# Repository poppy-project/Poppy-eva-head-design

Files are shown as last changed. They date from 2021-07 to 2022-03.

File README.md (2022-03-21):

# Poppy-eva-head-design

Raspberry Pi 4-based head design for Poppy Torso and Humanoid ; embedding a screen: the work was done by 3 students of the ENSAM Bachelor of technology at Bordeaux, France: Damien MARTY, Clément GEA and Éléa CHARPNTIER, under the supervison of Jean-Luc CHARLES and Cécile DELARUE, professors at ENSAM Bordeaux.

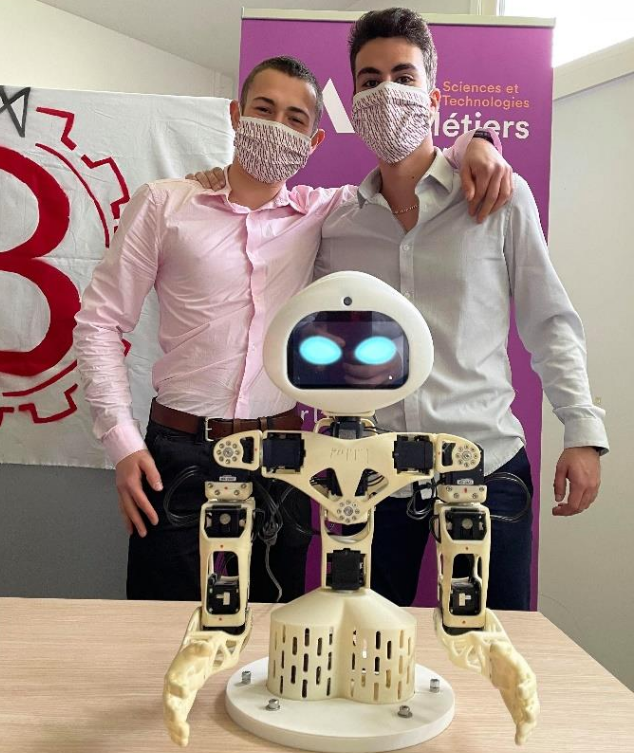
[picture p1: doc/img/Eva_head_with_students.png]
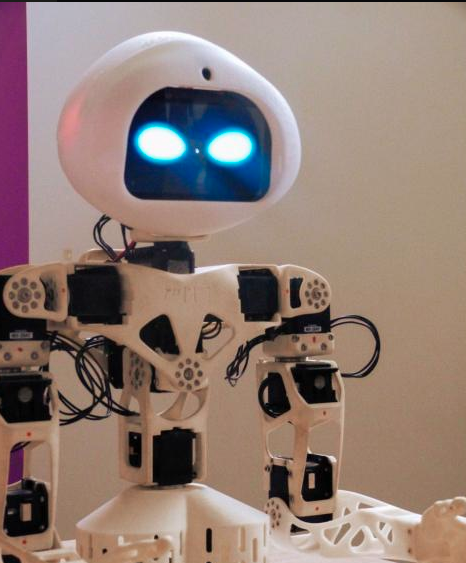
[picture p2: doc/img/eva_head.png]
  

This repository contains:

* `doc` contains the documentation files on the Poppy Eva head:
  * `Eva_head_design.pdf` gives the design history of the head Eva.
  * `Eva_head_assemby_procedure.md` is the assembly guide to make the Eva head for the Poppy Torso or Humanoid.
* `hardware`
  * `STL` : contains the STL files to print the four parts that make the Eva head.
  * `BOM.md`: the bill of material.
* `software`: contains the instructions to customize the file `config.txt` in the `boot` partition of the SD card in order to use the DSI connector of the RPI4 to connect the display screen. A full example of `config.txt` is also given.

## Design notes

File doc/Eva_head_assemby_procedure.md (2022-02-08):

# Eva-Head  assembly procedure

With [this bill of materials](../hardware/BOM.md), you should have all this material on the work bench:

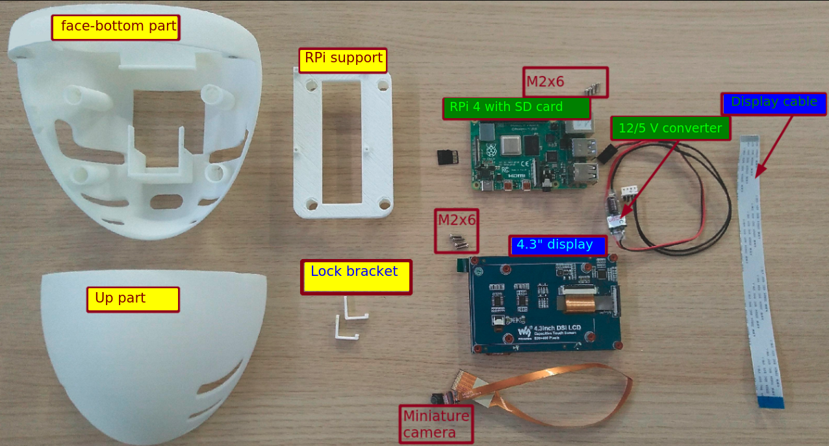
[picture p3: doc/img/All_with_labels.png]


## 1 - Preparing the head parts

Insert the miniature button magnets in the holes provided for this purpose in the _bottom/face_ and _upper_ parts.

WARNING: be careful with the magnet orientation while inserting them. __north__ and __south__ poles attract each other ensuring magnetic attraction between the the _up_ and _face-bottom_ parts, while __north__/__north__ or __south__/__south__ repel each other !

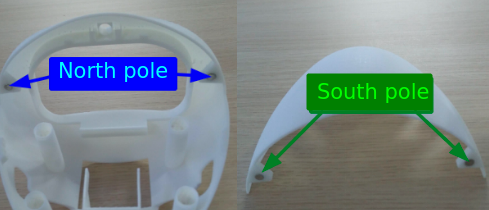
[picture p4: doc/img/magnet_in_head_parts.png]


## 2 - Fix the "bottom-face part" of the head to the AX-12 motor

- Insert the 8 x _M2 nuts_ in the reserved slots on the carter of the AX-12 motor

- Engage the "bottom-face part" of the head to align its fixing holes with those of the housing of the AX-12 motor.

- Gently tighten the 8 _M2x6_ screws:

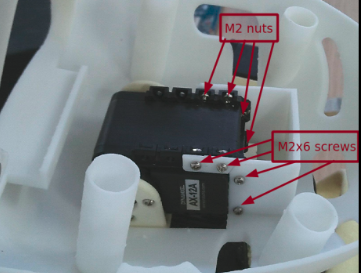
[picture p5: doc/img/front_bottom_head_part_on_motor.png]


## 3 - Preparing and installing the LCD display

- Gently pull the extremities of the _black lock bar_ of the DSI connector to open the connector.

- Insert the display cable with the contacts side of the cable oriented as shown in the image.
  
- Gently push the extremities of the _black lock bar_  to lock the cable inside the connector.

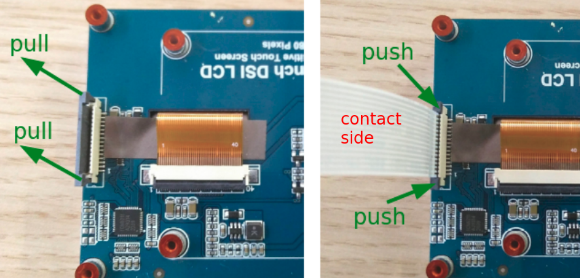
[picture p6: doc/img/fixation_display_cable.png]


When done, engage the screen in the "bottom-face part" of the head and lock the display with the the help of "removable glue pads" (_yellow patafix_) with the 2 _lock sliders_ :

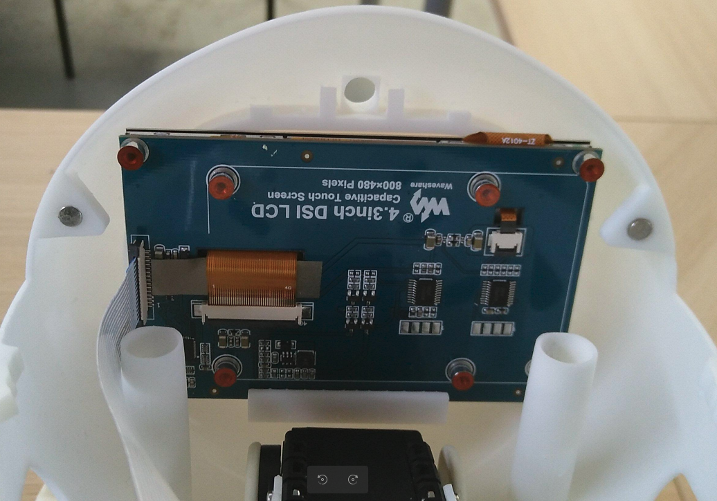
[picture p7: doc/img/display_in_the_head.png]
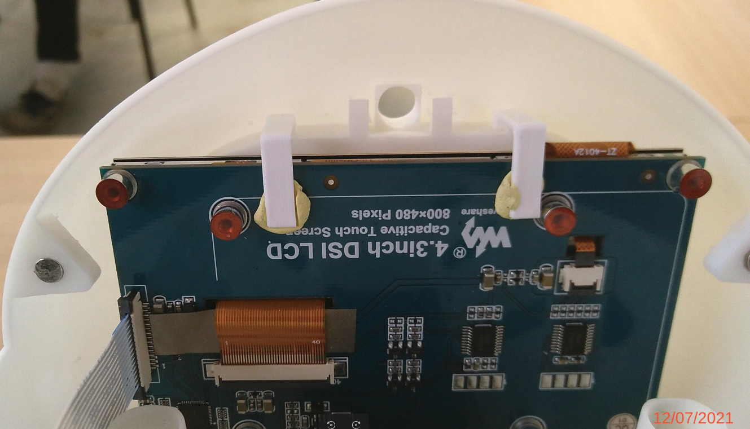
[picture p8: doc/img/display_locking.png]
 

## 4 - Fixing the camera in the head 

Insert the camera in the hole in the "bottom-face part" of the head:

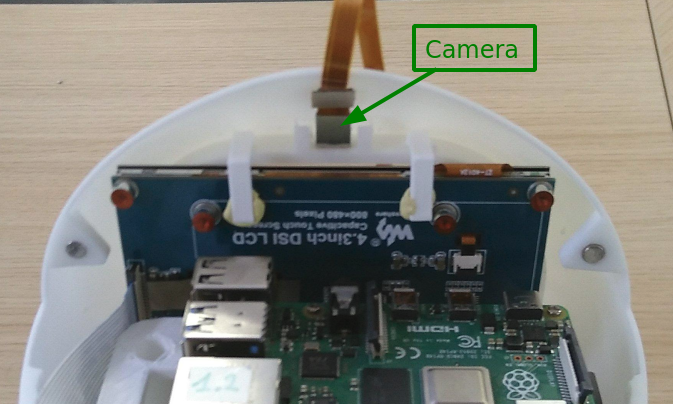
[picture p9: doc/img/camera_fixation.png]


## 5 - Preparing the RPi module

- You must flash the SD card to install a Linux distribution and the Poppy software: follow this [guide](https://github.com/poppy-project/poppy-docs/blob/master/en/installation/burn-an-image-file.md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).<br>Then you can insert the SD card in the SD slot of the RPi module.

- Place the RPi module on the "RPi support" part as shown in the image and gently tighten the 4 x M2x6 screws:

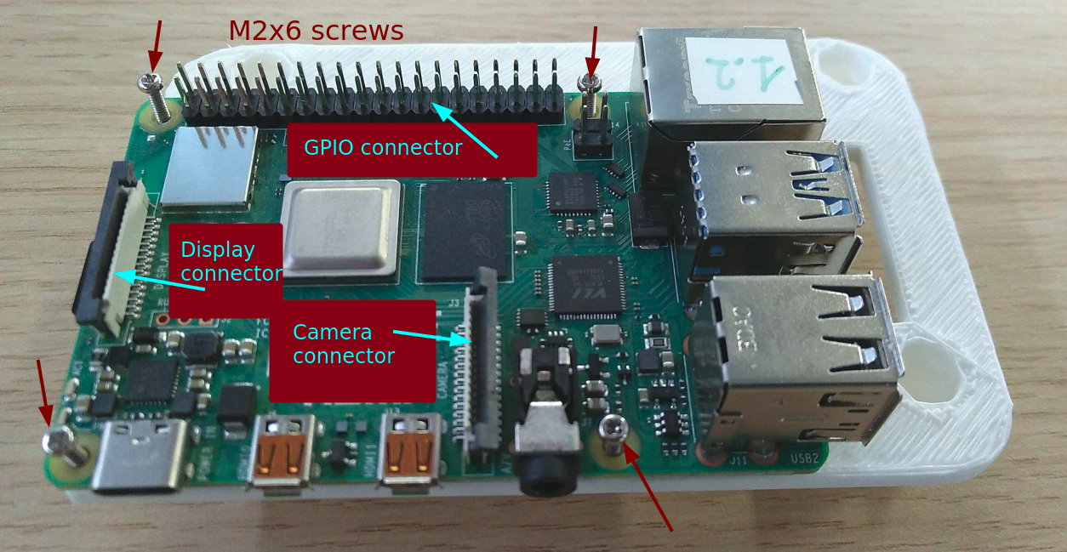
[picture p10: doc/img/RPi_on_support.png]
 

- When done, you can place the RPi support in the "bottom-face part" of the head, with the GPIO connector at the raer of the head.

## 6 - Final steps

- Connect the camera cable to the camera connector of the RPi module as shown in the image, with the contacts side of the cable facing the connector contacts (same gentle operation as in step 3).

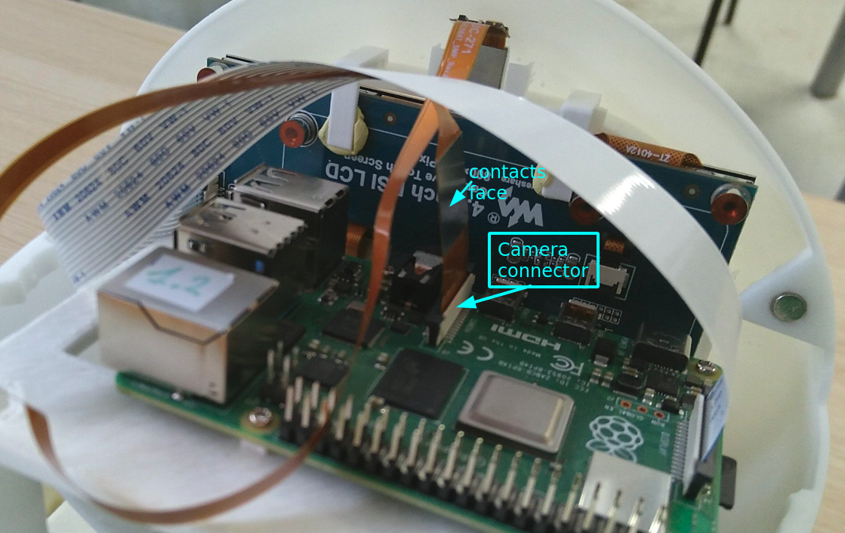
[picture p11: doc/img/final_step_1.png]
 

- Connect the display cable to the RPi display connector as shown in the image, with contact side of the cable facing the connector contacts.
  
- Connect the power connector to the GPIO connector of the RPi module as shown in the image.

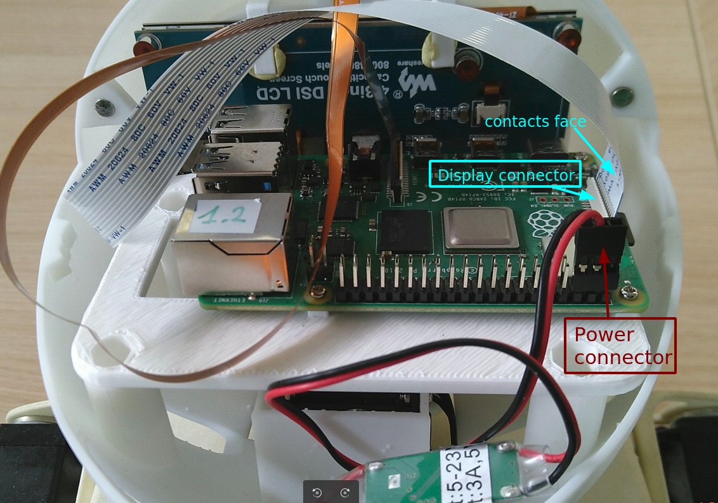
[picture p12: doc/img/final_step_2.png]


- Connect the USB2AXB to the USB port of the RPi module:
  
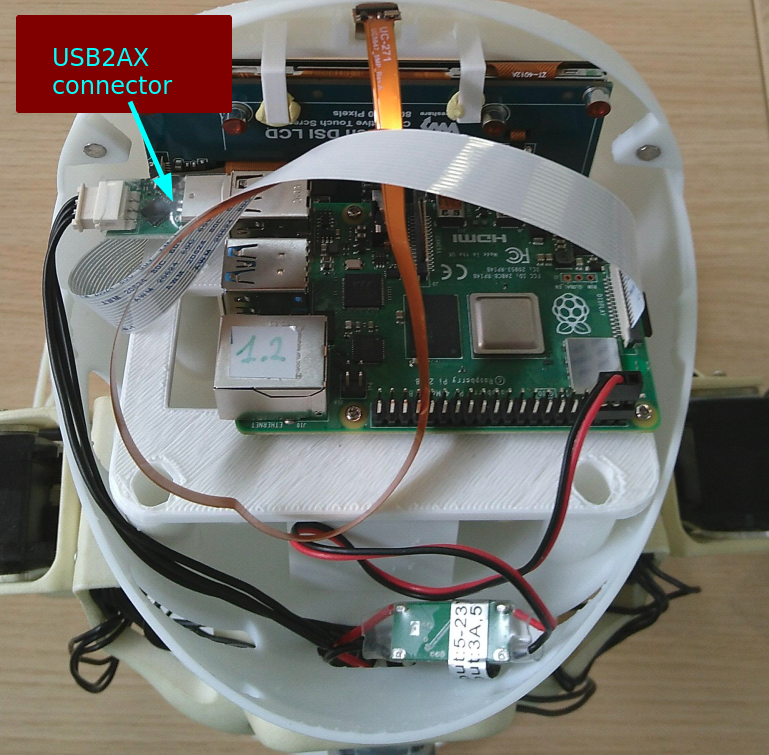
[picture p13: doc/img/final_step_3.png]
 

Et Voilà :smirk:

Close the head with the "upper part" : the Poppy _Eva head_ is ready ....

eva head

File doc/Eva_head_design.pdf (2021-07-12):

# POPPY

## Design of a new head

Damien MARTY
Clément GEA
Eléa CHARPENTIER
2020 / 2021 | 1

# Summary

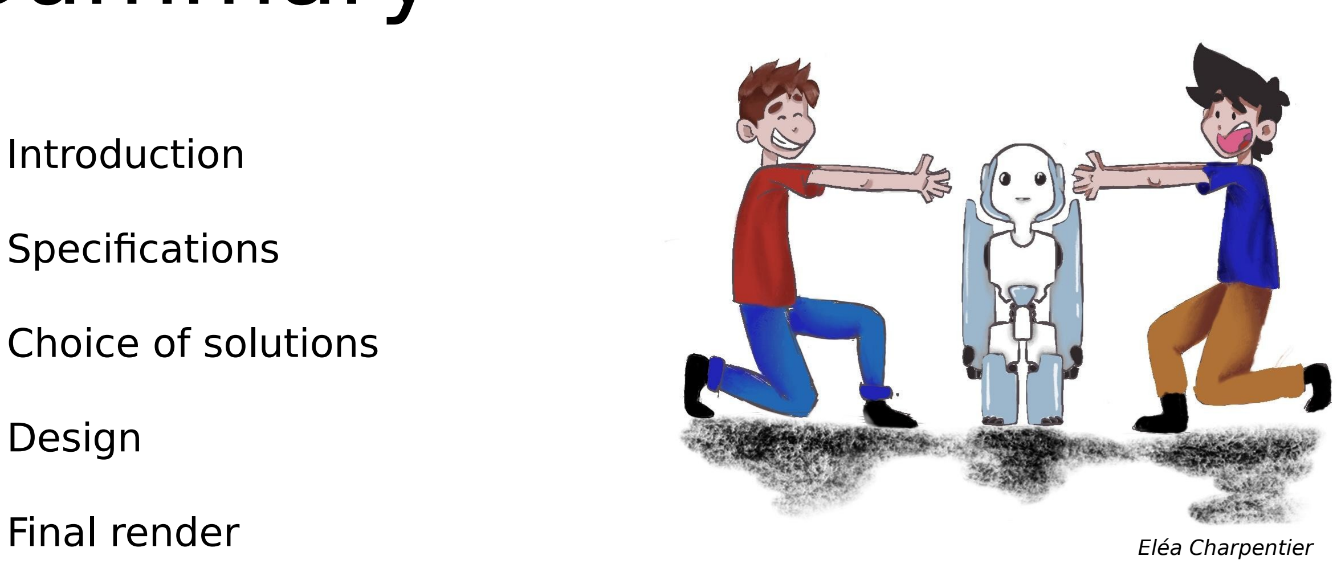
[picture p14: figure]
Final render; Eléa Charpentier

### Introduction

### Specifications

### Choice of solutions

### Design

# Specifications

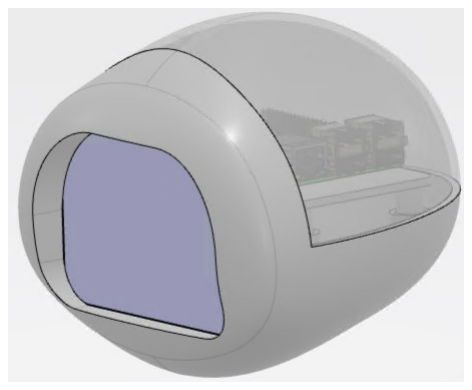
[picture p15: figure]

Retention of components in the head

Easy access to electronic components

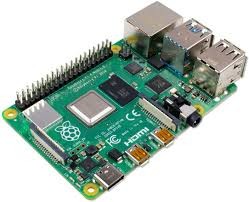
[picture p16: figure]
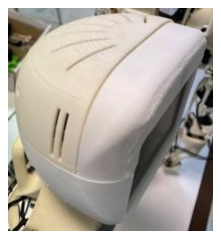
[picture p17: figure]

RPi 4

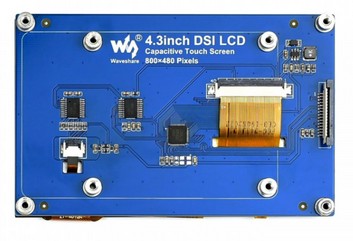
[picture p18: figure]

Display 4,3”

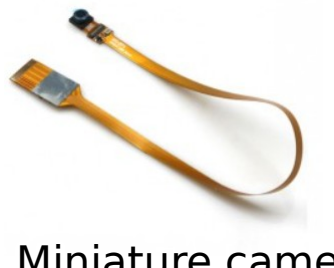
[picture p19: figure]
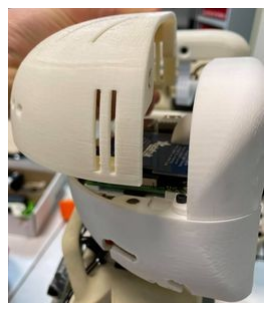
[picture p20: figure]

Miniature camera

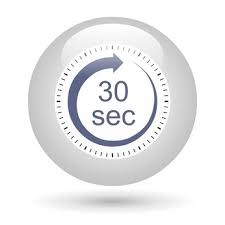
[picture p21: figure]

# Choice of solutions

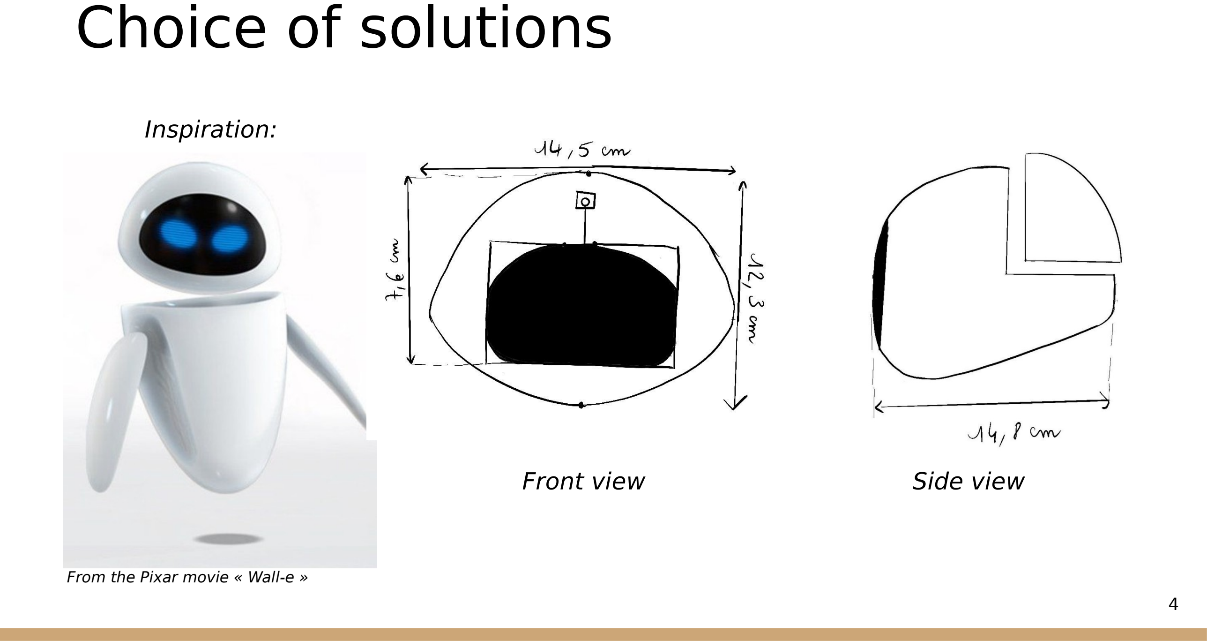
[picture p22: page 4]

From the Pixar movie « Wall-e »

Front view | Side view

Inspiration:

# Head parts fixation with magnets

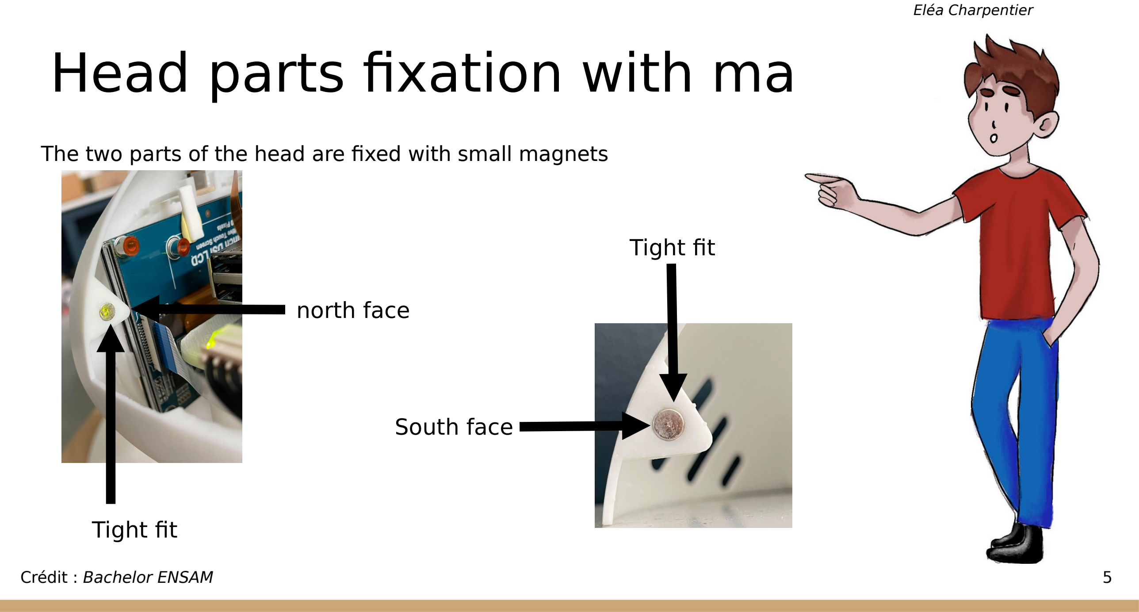
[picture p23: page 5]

The two parts of the head are fixed with small magnets

Eléa Charpentier

South face

Tight fit

Tight fit

north face

Crédit : Bachelor ENSAM

# Head shape

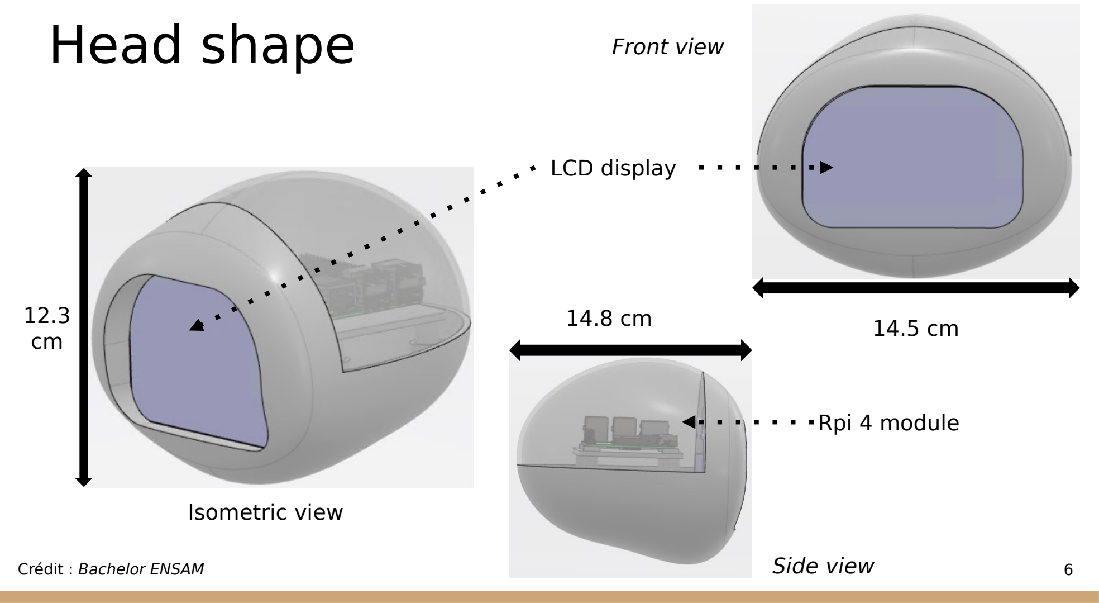
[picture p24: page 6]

Isometric view

Front view

Side view

LCD display

Rpi 4 module

12.3
cm
14.8 cm | 14.5 cm

Crédit : Bachelor ENSAM

# Rpi 4 integration

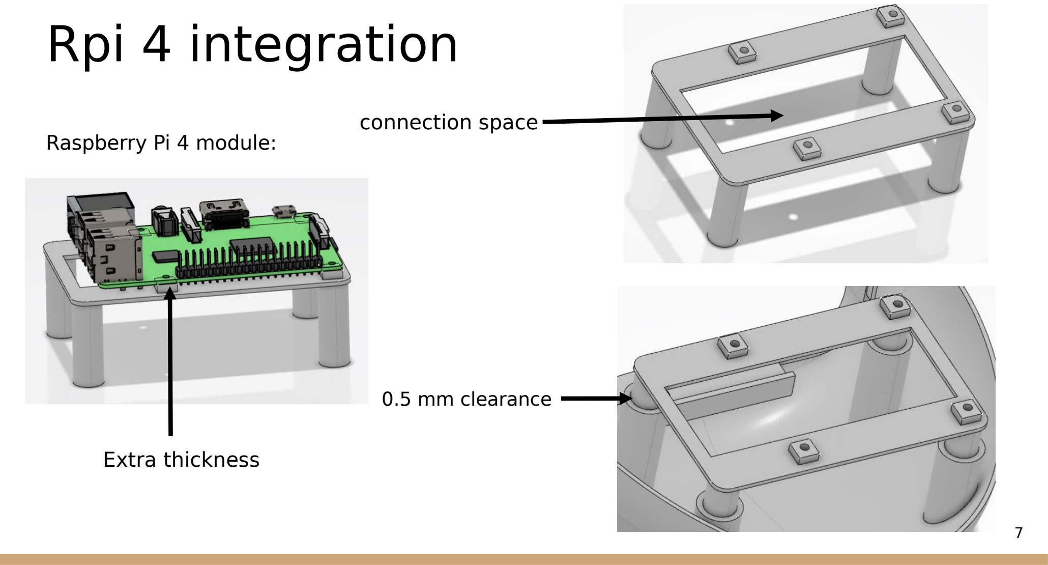
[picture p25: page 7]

Raspberry Pi 4 module:

0.5 mm clearance

Extra thickness

connection space

# LCD display integration

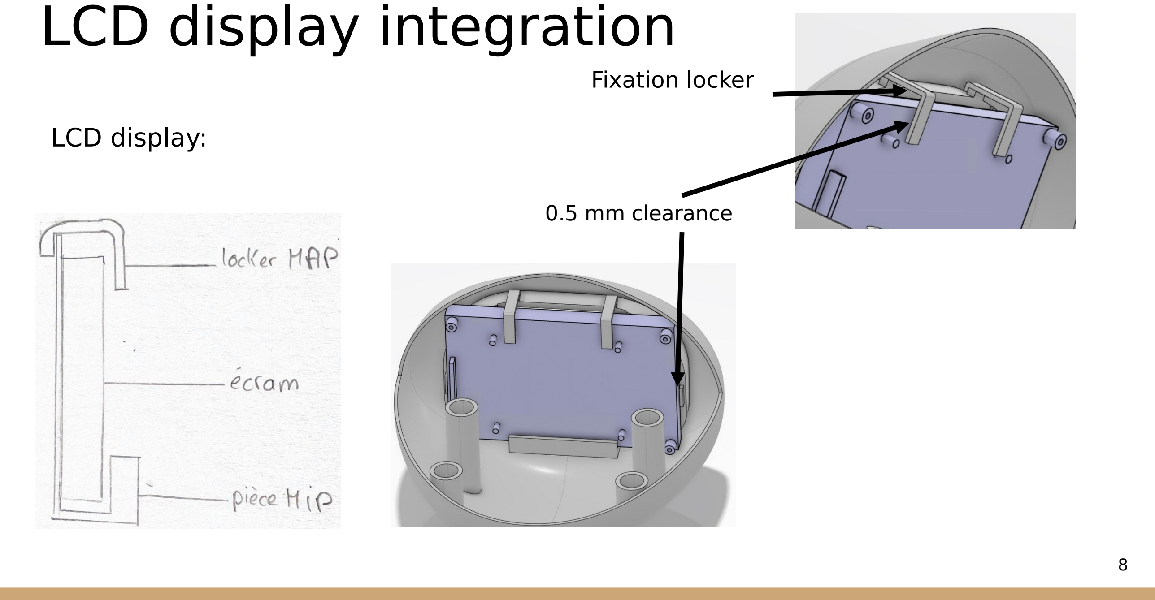
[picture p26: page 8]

LCD display:

Fixation locker

0.5 mm clearance

# Miniature camera integration


Miniature camera
Translation stops

centering cylinder

# Motor integration


Servomotor support

Dynamixel servomotor

Hole (servomotor assembing)

# Final render


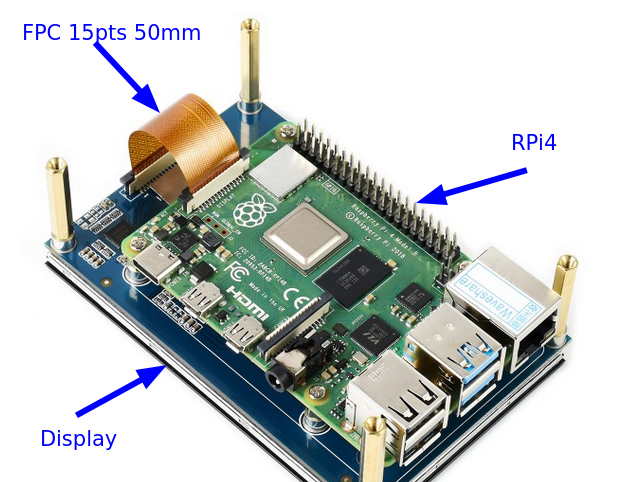
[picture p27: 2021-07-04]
hardware/img/display-RPi.png

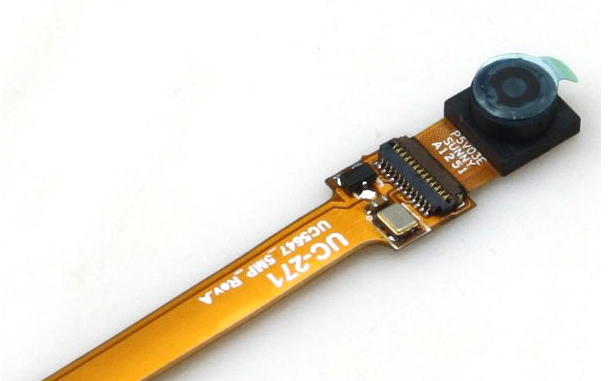
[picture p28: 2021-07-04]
hardware/img/camera_miniature.png

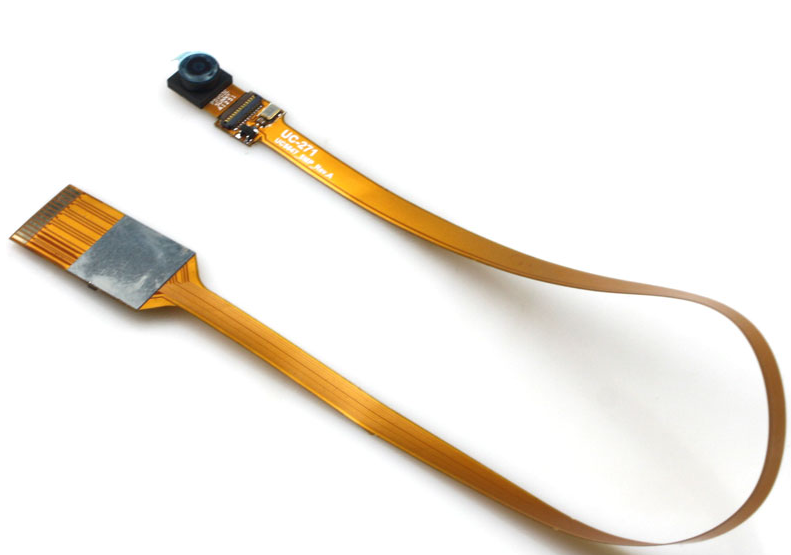
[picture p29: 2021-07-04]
hardware/img/camera_miniature_2.png

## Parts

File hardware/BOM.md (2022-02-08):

# BOM

For the head _eva_, you need the following material:

|  id | description | quantity |
| :---: | :--- | :---: |
|  1.1  | Raspberry Pi 4 module with its SD card | 1 |
|  1.2  | Power cable  using  a 12 V -> 6 V converter | 1 |
|  2.1  | 3.4 inch display 800x400 | 1 |
|  2.2  | 20 cm FPC 15PIN (Flexible Printed Circuits, opposite sides) cable to connect the display to the DSI port of the RPi | 1 |
| 3 | Miniature RPi camera B0066 | 1 |
| 4 | Miniature button magnets | 4 |
|  5.1  | Front-bottom part of the head (3D printed) | 1 |
|  5.2  | Top part of the head (3D printed) | 1 |
|  5.3  | RPi 4 support part (3D printed) | 1 |
|  5.4  | Locking brackets (3D printed) to lock the display in the head | 2 |
|  6.1  | M2x6 screws | 16 |
|  6.2  | M2 nuts | 8 |
| 7 | _glue pads_ (yellow Patafix) to maintain the locking brackets on the display. | 2 |

## 1/ Raspberry Pi 4 module

- You need a RPi4 module, with at least 2 GB RAM and a 16 GB SD card.

- In order to use the robot with the RPi4 the SD card must have a Linux OS and the Poppy software installed.

- To power the RPi4 from the 12 V power unit used for the robot motors, you must use a 12 V -> 5 V, 3A  converter like [this one available at generation robot](https://www.generationrobots.com/fr/402297-convertisseur-abaisseur-de-type-buck-ubec-dcdc-5v-3a-output.html).<br>
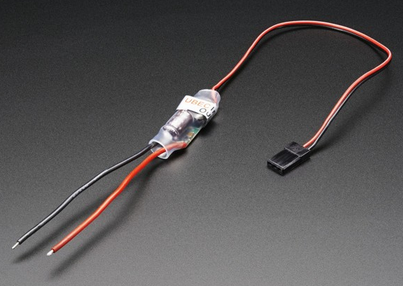
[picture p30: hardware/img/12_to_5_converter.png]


## 2/ 4.3inch Capacitive Touch Display, DSI Interface, 800×480

We have selected [this display](https://www.waveshare.com/product/raspberry-pi/displays/lcd-oled/4.3inch-dsi-lcd.htm?):

- Compatible with the DSI display interface of the Raspberry Pi.
- Resolution of 800x400 with touch control.
- Relatively cheap (~ 40 $ or 36 €).

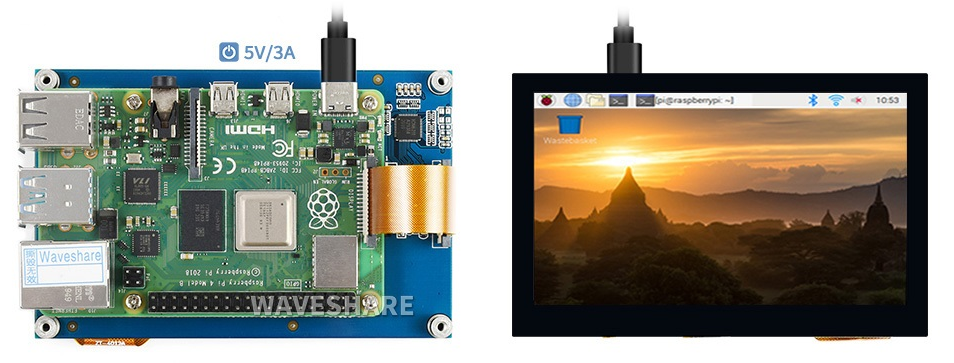
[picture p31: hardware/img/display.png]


As shown on the image, the RPi module can be attached directly to the back of the display, but for the Poppy usage, the display will be connected to the DSI connector using a 25 cm long FPC 15PIN (Flexible Printed Circuits, opposite sides).

The display is available for example from [www.waveshare.com](https://www.waveshare.com/product/raspberry-pi/displays/lcd-oled/4.3inch-dsi-lcd.htm?), and the flat flexibal cable is available for example from [FARNEL](https://www.newark.com/multicomp-pro/mp-ffca10152003b/cable-assy-ffc-ffc-15-core-200mm/dp/67AH2982?ost=3385343).

## 3/ Miniature camera 5 Mpx B0066

We have choosen [this model](https://www.arducam.com/spy-camera-raspberry-pi/) for its very small size and good technical characteristics. It is fuly compatible with the camera connector of the RPi module:

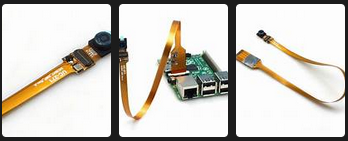
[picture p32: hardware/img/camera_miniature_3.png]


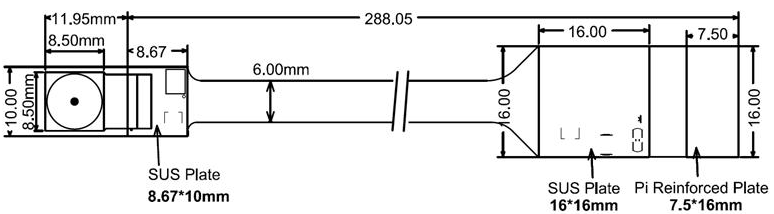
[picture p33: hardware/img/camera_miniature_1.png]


~ 35 € available for example at [www.generationrobots.com](https://www.generationrobots.com/en/402341-spy-camera-for-raspberry-pi.html), 
[www.gotronic.fr](https://www.gotronic.fr/art-module-camera-miniature-5-mpx-b0066-25255.htm) or [www.lextronic.fr](https://www.lextronic.fr/module-camera-spy-camera-5-mpx-pour-raspberry-pi-39137.html).

## 4/ Miniature button magnets

The button magnets are used for assembling the 2 parts of the head.
Dimensions:

- diameter: 6 mm
- thickness: 2.75 mm.

## 5/ STL parts

All the STL files are in the directory `STL`.

- the head is divided in 2 parts fixed with the miniature magnets :
  - the front/bottom part:<br>
`eva_head_frontBottom-part.stl`<br>
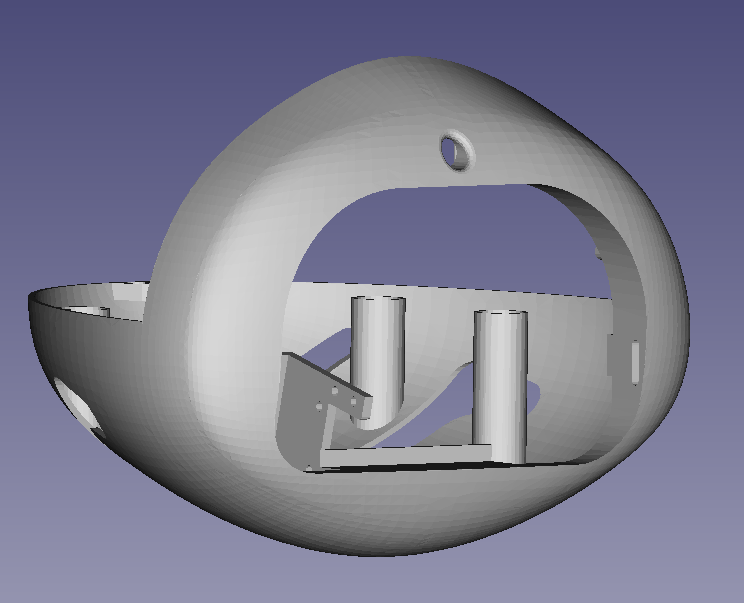
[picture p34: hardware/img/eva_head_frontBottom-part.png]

  
  - the top part:<br>
`eva_head_top-part.stl`<br>
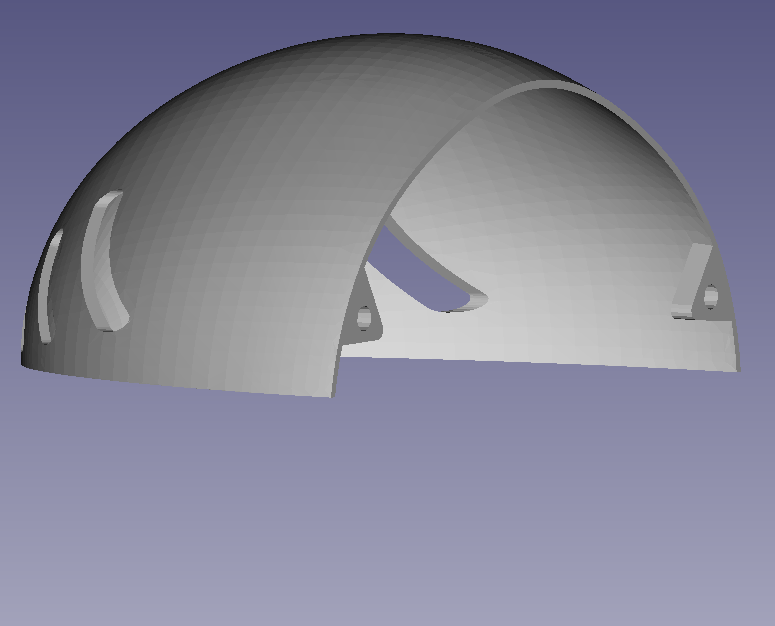
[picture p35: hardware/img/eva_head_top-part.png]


- the RPi4 support inserted in the frontBottom part:<br>
`eva_head_RPi4Support-part.stl`<br>
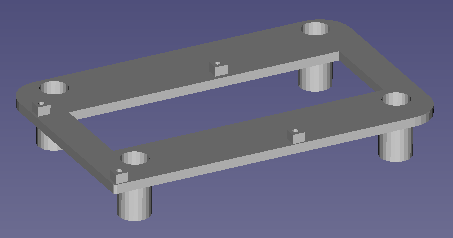
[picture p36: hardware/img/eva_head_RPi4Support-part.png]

  
- two "locking bracket" parts are used to lock the display in the head:<br>
`eva_head_lock-part.stl`<br>
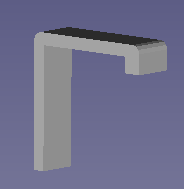
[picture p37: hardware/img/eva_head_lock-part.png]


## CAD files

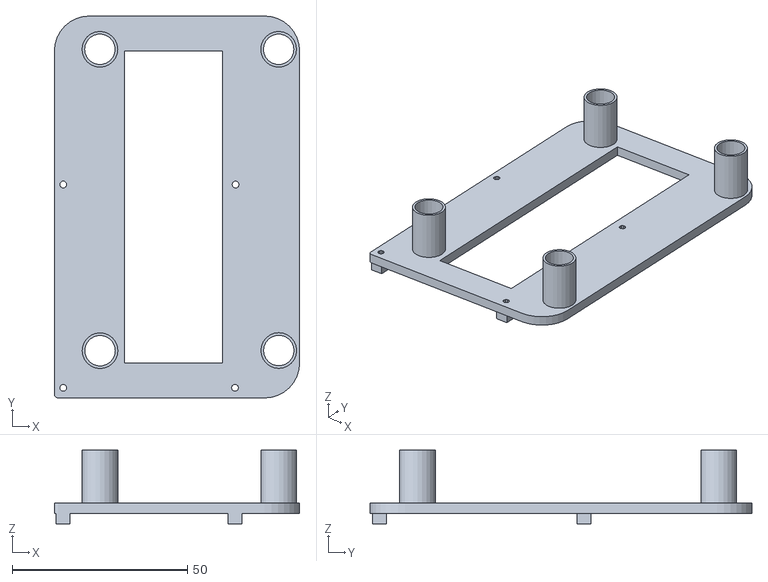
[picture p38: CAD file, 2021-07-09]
hardware/STL/eva_head_RPi4Support.stl
70.0 x 109.0 x 21.0

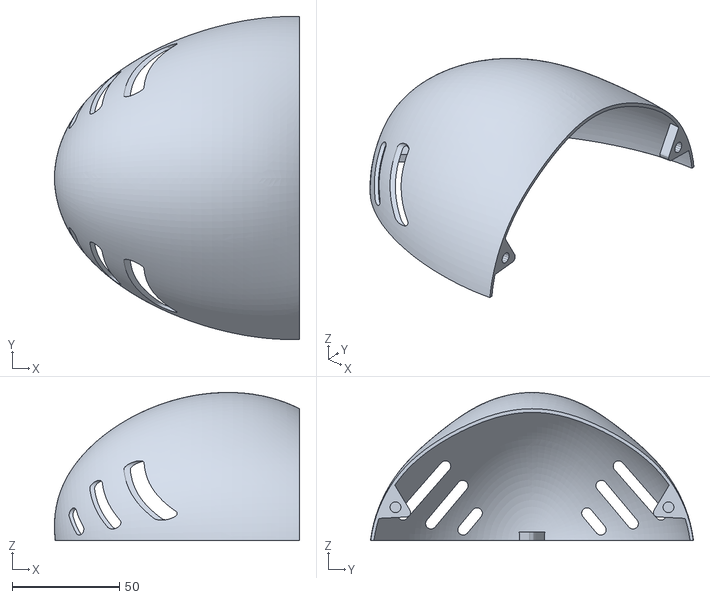
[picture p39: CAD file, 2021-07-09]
hardware/STL/eva_head_top-part.stl
114.1 x 150.3 x 68.9

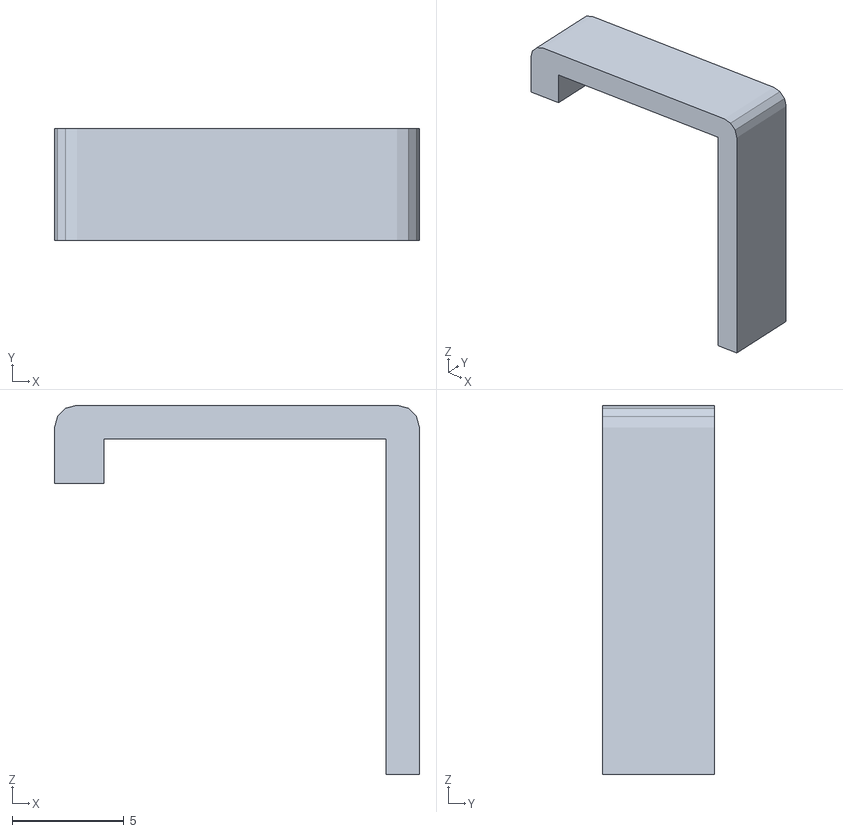
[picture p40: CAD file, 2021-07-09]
hardware/STL/eva_head_lock-part.stl
16.3 x 5.00 x 16.5

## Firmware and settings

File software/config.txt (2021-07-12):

# For more options and information see
# http://rpf.io/configtxt
# Some settings may impact device functionality. See link above for details

# uncomment if you get no picture on HDMI for a default "safe" mode
#hdmi_safe=1

# uncomment this if your display has a black border of unused pixels visible
# and your display can output without overscan
#disable_overscan=1

# uncomment the following to adjust overscan. Use positive numbers if console
# goes off screen, and negative if there is too much border
#overscan_left=16
#overscan_right=16
#overscan_top=16
#overscan_bottom=16

# uncomment to force a console size. By default it will be display's size minus
# overscan.
#framebuffer_width=1280
#framebuffer_height=720

# uncomment if hdmi display is not detected and composite is being output
#hdmi_force_hotplug=1

# uncomment to force a specific HDMI mode (this will force VGA)
#hdmi_group=1
#hdmi_mode=1

# uncomment to force a HDMI mode rather than DVI. This can make audio work in
# DMT (computer monitor) modes
#hdmi_drive=2

# uncomment to increase signal to HDMI, if you have interference, blanking, or
# no display
#config_hdmi_boost=4

# uncomment for composite PAL
#sdtv_mode=2

#uncomment to overclock the arm. 700 MHz is the default.
#arm_freq=800

# Uncomment some or all of these to enable the optional hardware interfaces
#dtparam=i2c_arm=on
#dtparam=i2s=on
#dtparam=spi=on

# Uncomment this to enable infrared communication.
#dtoverlay=gpio-ir,gpio_pin=17
#dtoverlay=gpio-ir-tx,gpio_pin=18

# Additional overlays and parameters are documented /boot/overlays/README

# Enable audio (loads snd_bcm2835)
dtparam=audio=on

[pi4]
# Enable DRM VC4 V3D driver on top of the dispmanx display stack
dtoverlay=vc4-fkms-v3d
max_framebuffers=2

[all]
#dtoverlay=vc4-fkms-v3d
disable_splash=1
start_x=1
gpu_mem=256

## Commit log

2021-07-09 Add STL files
    [eve_head_RPI4Support.stl, eve_head_locker.stl, eve_head_top-part.stl]
2021-07-12 Partial update from JLC
    [eve_head_lock-part.stl]
2021-07-12 Last update from JLC
    [config.txt, eve_head_RPi4Support.stl]
2022-01-12 Add rerefence for flot felxible cable FPC 15PIN
2022-02-08 change Eve in Eva
    [eva_head_RPi4Support.stl, eva_head_lock-part.stl, eva_head_top-part.stl]
